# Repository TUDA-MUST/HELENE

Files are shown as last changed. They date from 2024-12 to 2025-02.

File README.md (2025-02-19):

# HELENE - low cost 6DOF robot



Open the 3D model in your browser: https://a360.co/3EGeJgL

## Summary
This repo contains everything to build and use the low cost robot except the custom electronics, which can be [found in the seperate repo right here](https://github.com/SrSupp/Helene_electronics)
All files and an assembly guide can be found in the hardware_build directory.
### Get started
You can either run the robot itself, or a simulation.

## Simulation
Start the simulation environment:
```
roslaunch moveit_helene start_gazebo.launch 
```
Afterwards start moveit: 
```
roslaunch moveit_helene start_moveit.launch 
```

## Real Robot

You need:
-Robot itself. [See building instructions](hardware_build/AssemblyManualOnline.pdf) \
-Ubuntu or Debian machine running ROS melodic or noetic with this package. Noetic is preferred! [See installation guide](ROS_InstallationGuide.md)\
-24v Power supply \
-USB Cable 

To start the robot arm connect Helene to 24V and wait until it is fully aligned. Only then can the robot arm be connected to the computer via the USB cable! 
A terminal can then be started on the computer (Preffered!). Via the command: 

```
roslaunch applications_helene realrobot.launch 
```

the connection is established automatically, the PID controller and MoveIt are started. 

Alternatively, this can also be done separately via the commands: 
```
$ roslaunch controller_helene robot.launch 
$ roslaunch moveit_helene hardware_interface.launch 
$ roslaunch moveit_helene demo.launch 
```
each of which must be executed in a new terminal. 

## Start Demo
In applications_helene you can find 2 simple nodes to control the robot. Run using:
```
$ rosrun applications_helene demoSpiral 
$ rosrun applications_helene demoSpeed
```
demoSpiral draws a spiral, demoSpeed executes the same trajectory in full and reduced speed.

## Python Interface

Inside the applications_helene\scripts folder is the Python library helpy, which allows easy programming of the robot arm. An example is located in main. When the example is executed, the robot arm should move and also the LEDs should light up. Use this script as inspiration and show what the robot arm can do!\
We use the PyCharm IDE for Python programming, with which the created scripts can be executed directly. This is also great for students. 
Without an IDE, the script main can be executed by the command: 
```
python3 main.py
```

## jog Arm with a joystick/spacemouse or published EEF velocities
You probably need to modify /moveit_helene/config/helene_servoing.yaml 

- launch either Gazebo or the real robot
- move out of singularity, if starting in one

**switch from trajectory controller to group controller**
```
rosservice call helene/controller_manager/switch_controller "start_controllers: ['effort_group']
stop_controllers: ['arm_controller']
strictness: 2
start_asap: false
timeout: 0.0" 
```
**run the servo node**
```
roslaunch moveit_helene spacenav_cpp.launch 
```

### Support for custom end effectors

The robot supports the use of custom end effectors. These end effectors can be used by adding the argument "end_effector:=END_EFFECTOR_NAME", when launching the robot.

For more information regarding custom end effectors see the [corresponding documentation](helene_ros/src/end_effectors/custom_end_effectors.md).

### Troubleshooting

If you encounter problems while compiling the ESP projects and get an error due to missing ros_lib headers, try building your customized libs like this:

```
cd <Path to the failing project>/lib
rm -rf ros_lib 
rosrun rosserial_arduino make_libraries.py .
```

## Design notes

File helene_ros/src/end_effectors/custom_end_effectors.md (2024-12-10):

# Custom end effectors for HELENE

## Usage

The helene robot supports the use of custom end effectors. These end effectors can be used by adding the argument "end_effector:=END_EFFECTOR_NAME", when launching the robot.

Here are two examples:
```
roslaunch applications_helene simulation.launch end_effector:=led_head
roslaunch applications_helene realrobot.launch end_effector:=needle
```

## Creating/adding custom end effectors

You can create or add new custom end effectors to the robot. This is done by adding a new ROS package containing the urdf description.

### Package structure
The package should have the following structure:
The name of the package should be the same name as your end effector.
For a clear project structure it is preferable to locate the package inside the /end_effectors folder, although this is not mandatory.
The package must contain a folder called urdf.
Inside this folder the description of your end effector must be stored in a file called: "END_EFFECTOR_NAME.urdf.xacro".

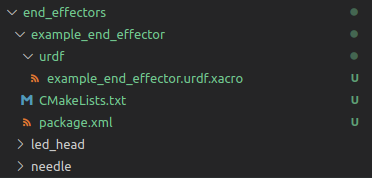
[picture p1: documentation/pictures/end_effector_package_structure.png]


If you want to use a package that does not have the same name as your end effector, you have to specify its name by adding the argument "end_effector_package:=END_EFFECTOR_PACKAGE", when launching the robot.
```
roslaunch applications_helene simulation.launch end_effector:=led_head end_effector_package:=example_package
```

### End effector description

To attach your end effector to the robot, your urdf.xacro file must include a static joint connecting your end effector with the last link of the helene robot arm (axis_0).
When defining this link, make sure that your geometry does not interfere with the geometry of the arm, as this can lead to problems with moveit path planning (0.1mm of clearance is usually sufficient).
You should also be aware that the current moveit configuration only works with static end effectors. If you want to use a dynamic end effector like a gripper, you will have to create and integrate a new moveit configuration.

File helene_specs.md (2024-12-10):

# Specifications

## Workspace

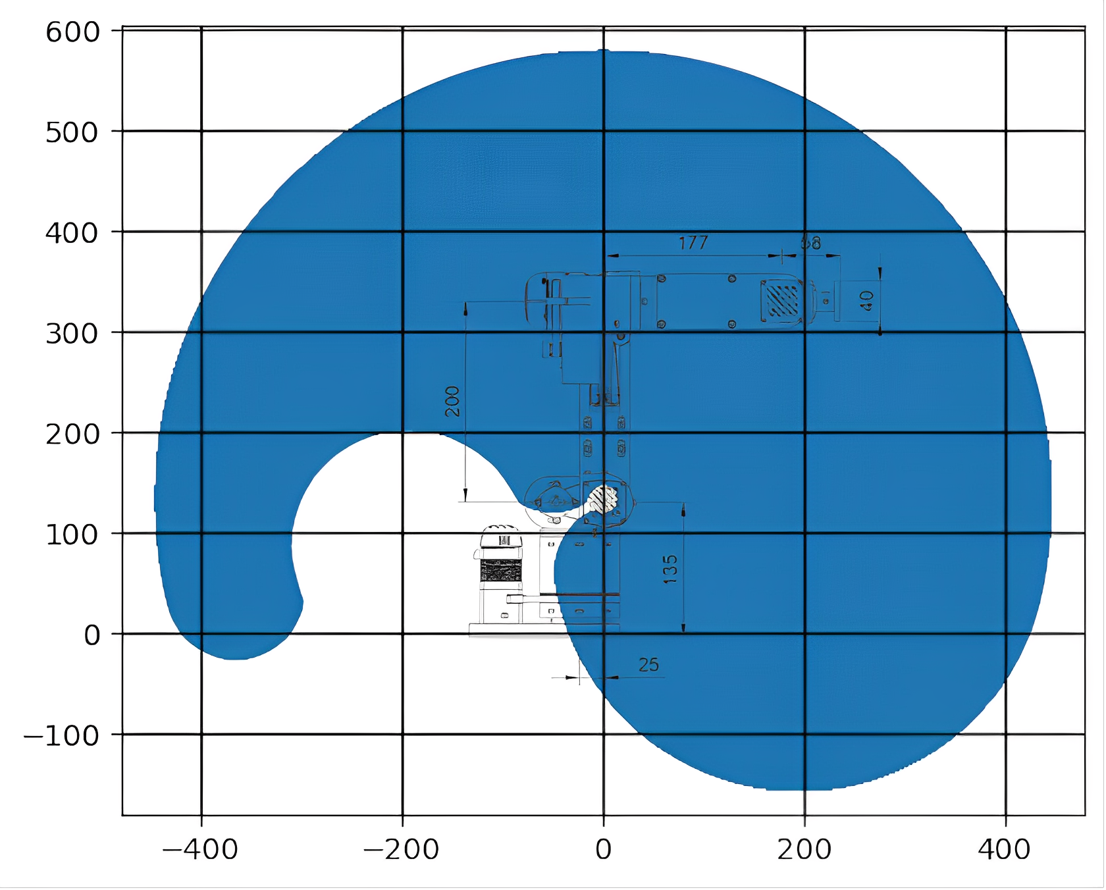
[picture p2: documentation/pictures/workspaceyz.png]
 
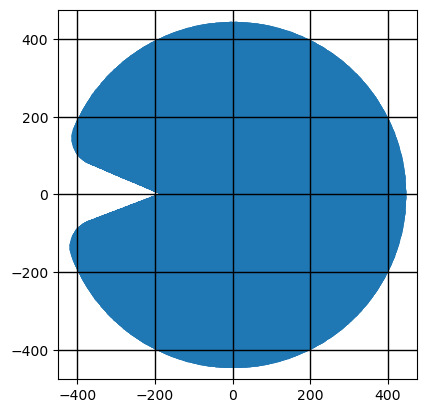
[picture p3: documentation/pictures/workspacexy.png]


The workspace in the yz- and xy-planes. 

Joint limits:

| (degrees) | 1 | 2 | 3 | 4 | 5 | 6 |
| --- | ----- | ----- | --- | ----- | ----- | ----- |
| | \-160 | \-105 | 0 | \-166 | \-155 | \-180 |
| | 160 | 105 | 160 | 166 | 155 | 180 |

## Accuracy and Precision

Accuracy and precision measurements are carried out according to ISO 9283, with small adjustments to the points. 

The following points in Helene coordinates (mm) are used:

| (mm) | home | 1 | 2 | 3 | 4 | 5 |
| ---- | ---- | --- | --- | ----- | ----- | ----- |
| x | 247  |  326.2 | 36.3 | 181.5 | 326.7 |  36.3 |
| y | 0  | -145.2 | -145.2 | 0 | 145.2 | 145.2 |
| z | 345  |  76.3  |  366.7 | 221.5 | 76.3  | 366.7 |

### Repeatability

| (mm)  | home  | 1 | 2 | 3 | 4 | 5 | average |
| ----- | ----- | ----- | ----- | ----- | ----- | ----- | --- |
| x | 0.14  | 0.269 | 0.256 | 0.089 | 0.688 | 0.754 | |
| y | 0.173 | 0.155 | 0.116 | 0.111 | 0.837 | 2.556 | |
| z | 0.255 | 0.131 | 0.111 | 0.112 | 0.69  | 0.813 | |
| total | 0.338 | 0.337 | 0.302 | 0.181 | 1.285 | 2.786 |  **0.872** |

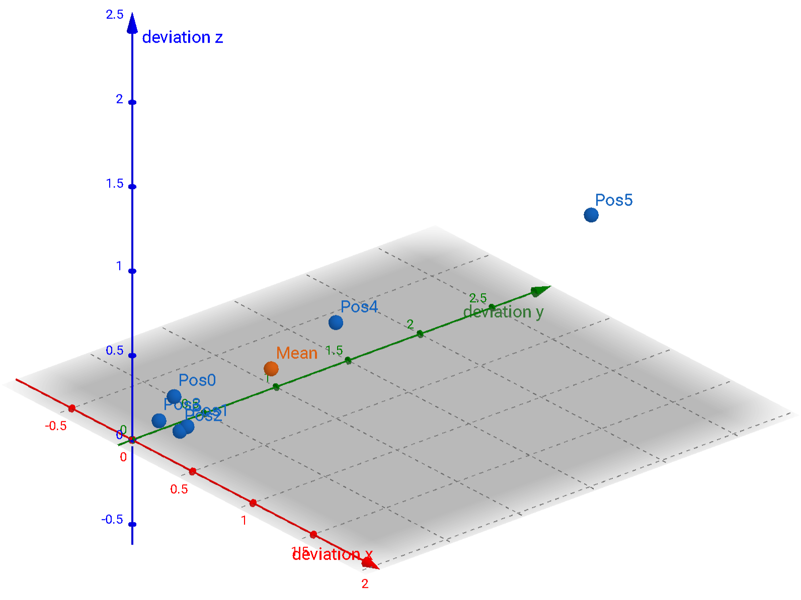
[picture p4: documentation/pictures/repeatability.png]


### Positional Accuracy

The positional accuracy is evaluated at the same positions as repeatability. The home position of Helene is assumed to be true, and positions are evaluated relative to it.

| (mm)  | 1 | 2 | 3 | 4 | 5 | average |
| ----- | --- | --- | --- | --- | --- | --- |
| x | -1.615 |  5.228 |  0.204 | -8.302 |  6.085 | |
| y |  9.178 | -3.643 | -4.362 | -0.038 | 10.397 | |
| z | -2.919 |  2.646 | -2.133 |  0.776 | -1.148 | |
| total |  9.765 |  6.900 |  4.860 |  8.338 | 12.101 |  **8.393** |

Thank you to WENZEL Group for allowing us to use their coordinate measuring machines and assisting in the evaluation of the robot. 

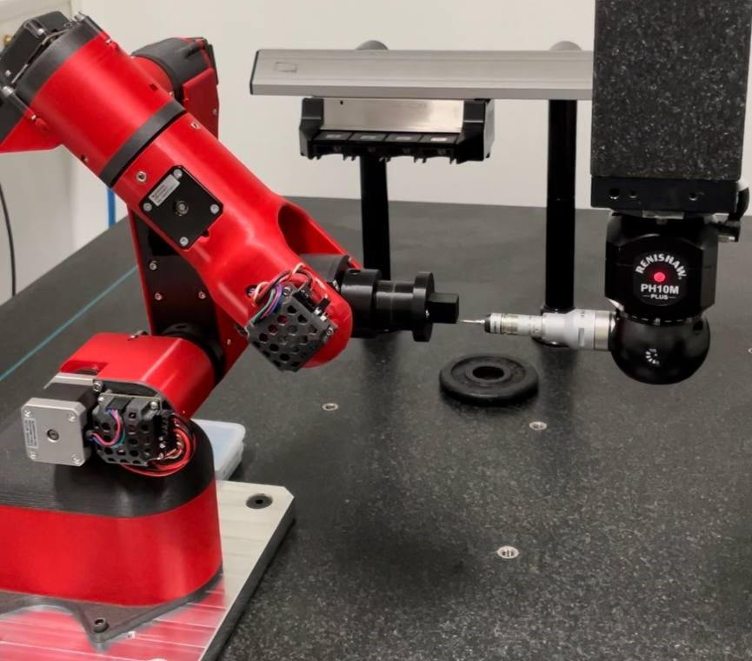
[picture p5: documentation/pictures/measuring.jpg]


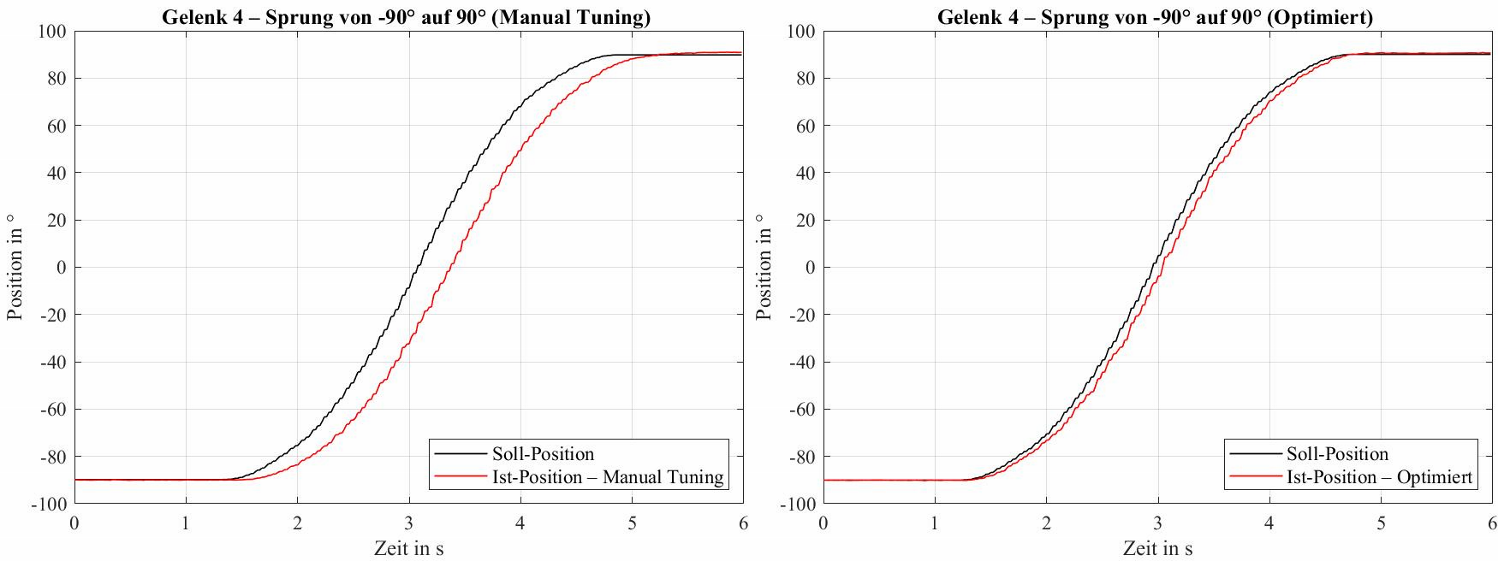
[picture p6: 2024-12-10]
documentation/pictures/controller_comparison.PNG

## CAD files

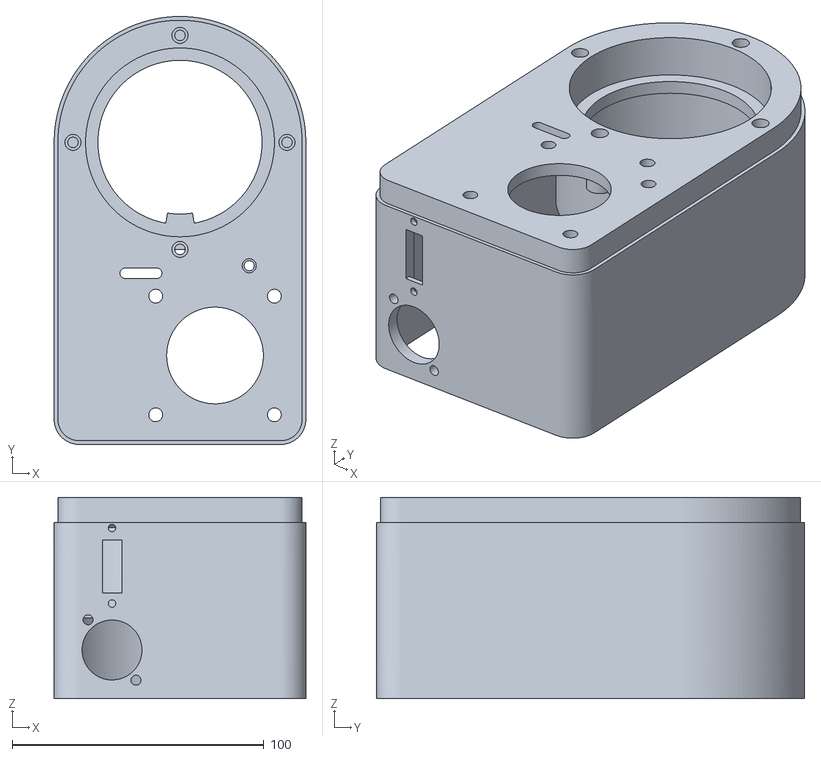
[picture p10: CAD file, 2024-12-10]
hardware_build/print files/col1/B1_Basis_Main.stl
100.0 x 170.0 x 80.0

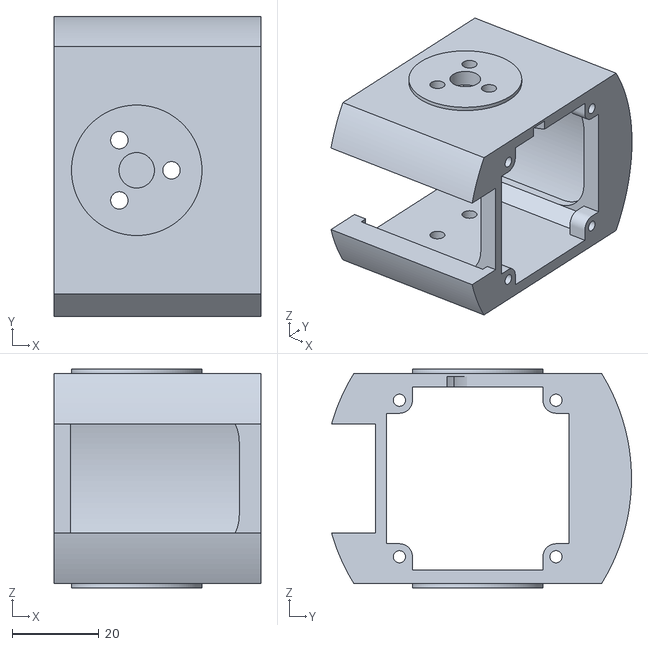
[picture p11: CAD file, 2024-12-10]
hardware_build/print files/col2/B33_Gelenk6_main.stl
47.6 x 69.0 x 50.3

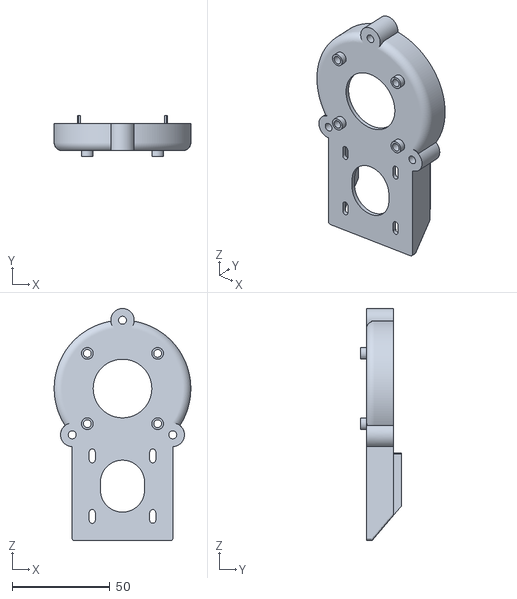
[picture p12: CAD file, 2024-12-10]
hardware_build/print files/col2/B25_Gelenk4_Motorhalter.stl
70.0 x 21.0 x 118.8

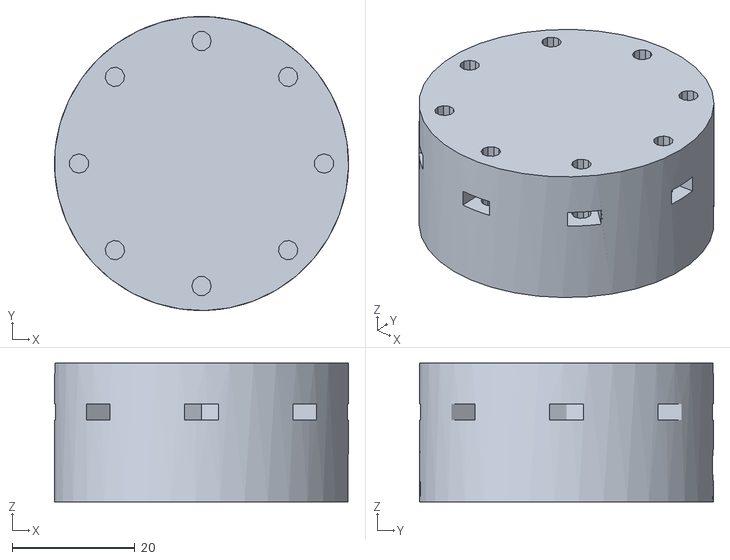
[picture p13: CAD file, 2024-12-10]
helene_ros/src/hw_description/meshes/Flansch.stl
48.0 x 48.0 x 22.7

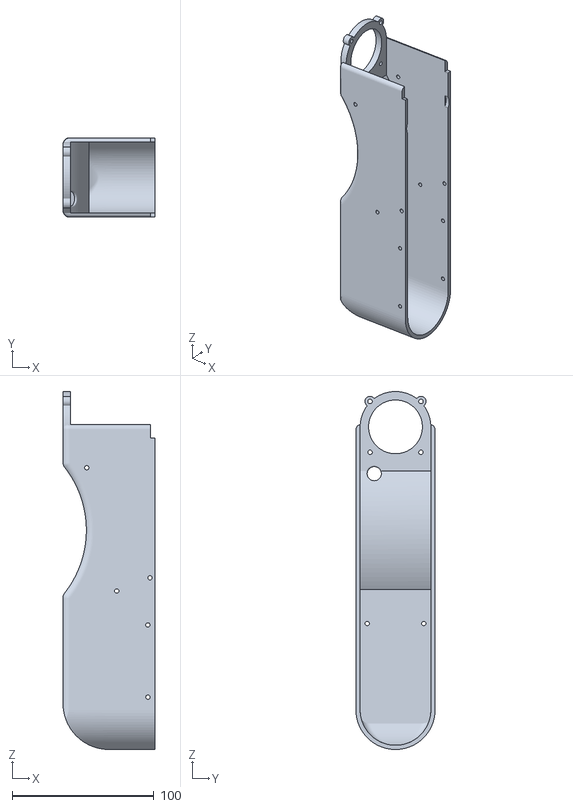
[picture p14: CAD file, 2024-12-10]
hardware_build/print files/col1/B22_Gelenk3_Deckel.stl
65.0 x 56.0 x 253.0

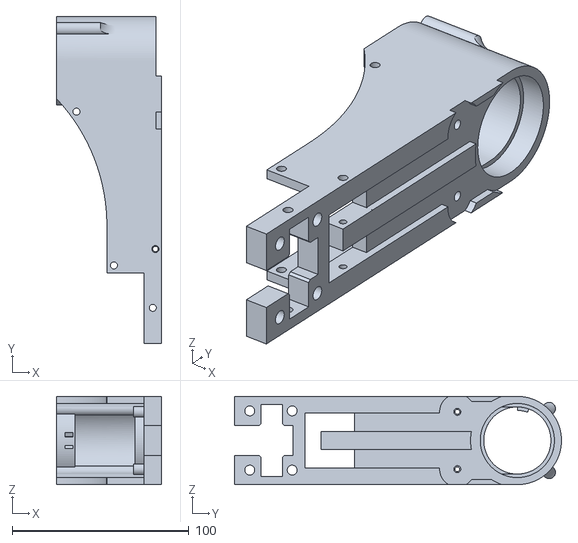
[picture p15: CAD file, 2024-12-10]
hardware_build/print files/col2/B16_Gelenk3_Hauptteil_Oben.stl
59.6 x 185.2 x 50.0

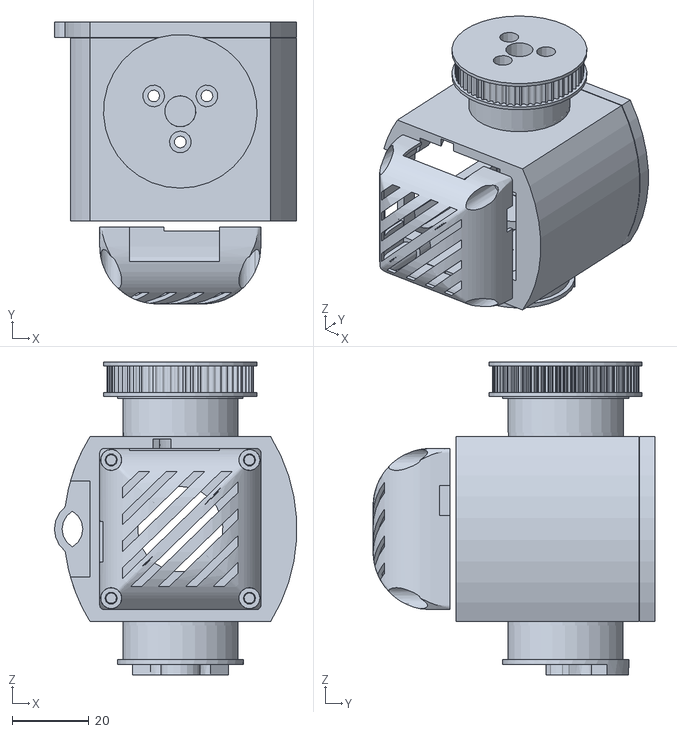
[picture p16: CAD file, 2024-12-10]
helene_ros/src/hw_description/meshes/Komponente6.stl
63.1 x 73.4 x 81.5

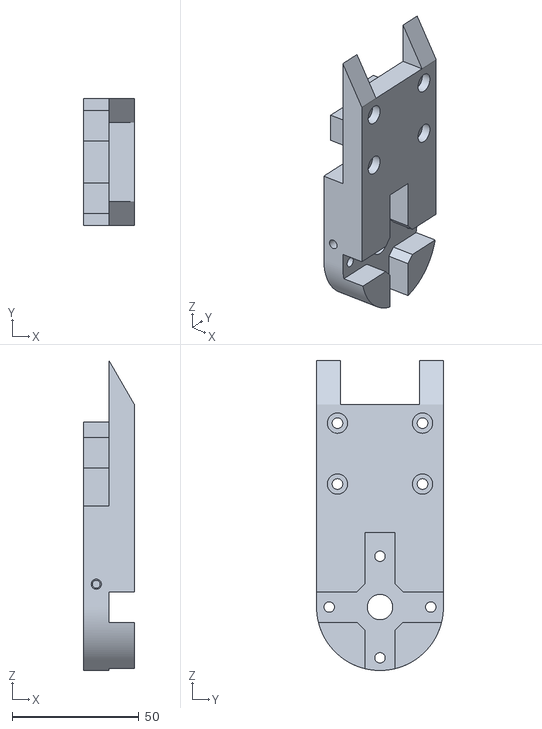
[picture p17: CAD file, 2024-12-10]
hardware_build/print files/col2/B15_Gelenk3_Hauptteil_Unten.stl
20.0 x 50.0 x 122.1

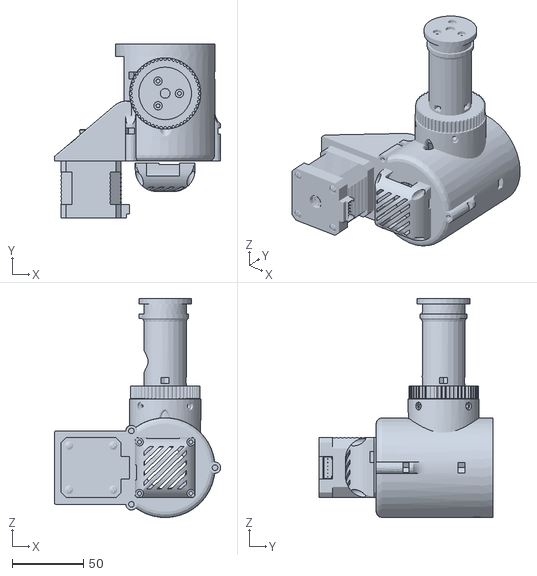
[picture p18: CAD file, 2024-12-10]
helene_ros/src/hw_description/meshes/Komponente4.stl
116.8 x 122.4 x 153.7

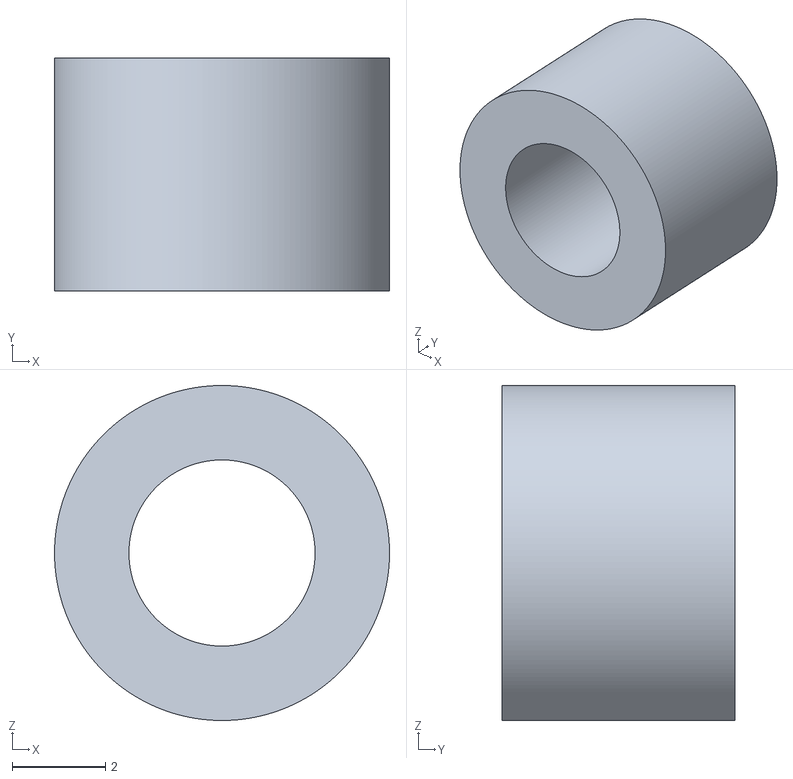
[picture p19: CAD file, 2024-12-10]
hardware_build/print files/col2/B36_Lagerabstand.stl
7.20 x 5.00 x 7.20

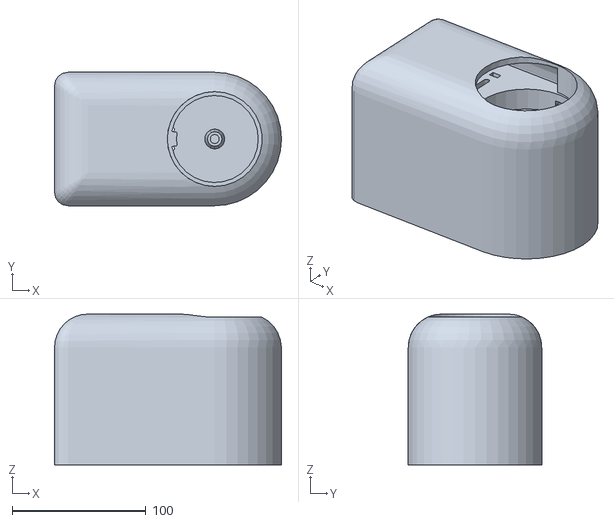
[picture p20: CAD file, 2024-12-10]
helene_ros/src/hw_description/meshes/Komponente1.stl
170.0 x 100.0 x 113.0

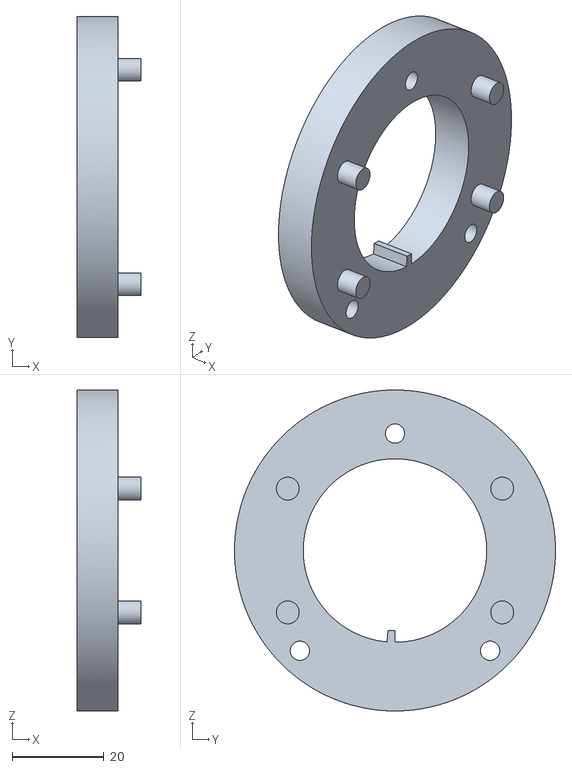
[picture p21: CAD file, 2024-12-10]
hardware_build/print files/col2/B27_Gelenk4_Lagerdeckel.stl
14.0 x 70.0 x 70.0

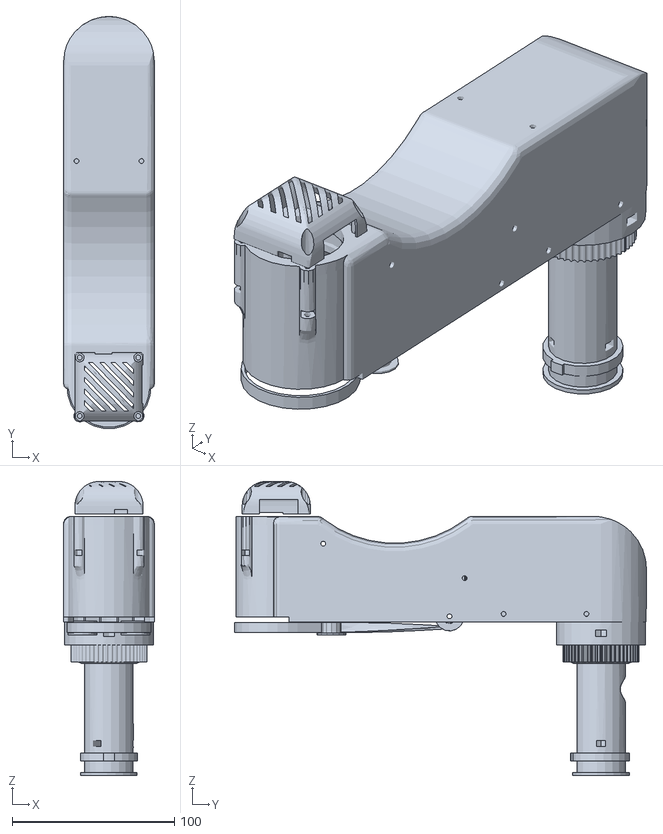
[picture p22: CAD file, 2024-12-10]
helene_ros/src/hw_description/meshes/Komponente3.stl
56.0 x 253.7 x 181.1

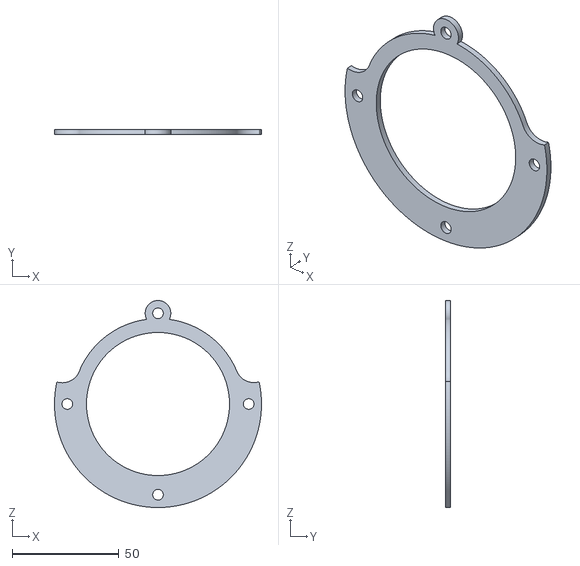
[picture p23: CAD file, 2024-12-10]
hardware_build/print files/col2/B3_Basis_Lagerdecke.stl
97.0 x 2.50 x 97.0

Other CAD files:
helene_ros/src/hw_description/meshes/Komponente5.stl
hardware_build/print files/col2/B34_Gelenk6_Deckel.stl
hardware_build/print files/col2/B20_Gelenk3_Welle_Abschluss.stl
hardware_build/print files/col2/B6_Basis_Pulley_klein2.stl
hardware_build/print files/col2/B12_Gelenk2_Festlager_Gelenkfassung.stl
hardware_build/print files/col2/B13_Gelenk2_Welle_Abschluss.stl
hardware_build/print files/col2/B14_Gelenk2_Lagerdecke.stl
hardware_build/print files/col2/B21_Gelenk3_Motorhalter.stl
hardware_build/print files/col2/B26_Gelenk4_Pulley.stl
hardware_build/print files/col2/B28_Gelenk4_5_Ubergang.stl
hardware_build/print files/col2/B30_Gelenk5_Welle.stl
hardware_build/print files/col2/B35_Deckel_Elektronik.stl
hardware_build/print files/col2/B5_Basis_Pulley_klein.stl
hardware_build/print files/col2/B7_Basis_Bodenplatte.stl

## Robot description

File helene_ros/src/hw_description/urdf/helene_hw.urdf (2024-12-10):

<?xml version="1.0" ?>
<robot name="helene">
    <link name="world" />

  <joint name="world_to_base_link" type="fixed">
    <parent link="world"/>
    <child link="base_link"/>
  </joint>
    <link name="base_link">
        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
        
<inertial>
            <mass value="0.8" />
            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
        </inertial>

    </link>
    <link name="axis_0">
        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
        
<inertial>
            <mass value="0.8" />
            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
        </inertial>

    </link>
    <joint name="q1" type="revolute">
        <axis xyz="0 0 1" />
        <limit effort="1000.0" lower="-2.79" upper="2.79" velocity="5" />
        <origin rpy="0 0 0" xyz="0 0 0" />
        <parent link="base_link" />
        <child link="axis_0" />
    </joint>
    <link name="axis_1">
        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
        
<inertial>
            <mass value="0.8" />
            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
        </inertial>

    </link>
    <joint name="q2" type="revolute">
        <axis xyz="0 0 1" />
        <limit effort="1000.0" lower="-1.83" upper="1.83" velocity="5" />
        <origin rpy="-1.571 0 0" xyz="0.02 0 0.145" />
        <parent link="axis_0" />
        <child link="axis_1" />
    </joint>
    <link name="axis_2">
        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
        
<inertial>
            <mass value="0.8" />
            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
        </inertial>

    </link>
    <joint name="q3" type="revolute">
        <axis xyz="0 0 1" />
        <limit effort="1000.0" lower="0" upper="2.7925" velocity="5" />
        <origin rpy="0 0 3.141" xyz="0 -0.200 0" />
        <parent link="axis_1" />
        <child link="axis_2" />
    </joint>
    <link name="axis_3">
        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
        
<inertial>
            <mass value="0.8" />
            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
        </inertial>

    </link>
    <joint name="q4" type="revolute">
        <axis xyz="0 0 1" />
        <limit effort="1000.0" lower="-2.9" upper="2.9" velocity="5" />
        <origin rpy="-1.571 0 0" xyz="0 0 0" />
        <parent link="axis_2" />
        <child link="axis_3" />
    </joint>
    <link name="axis_4">
        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
        
<inertial>
            <mass value="0.8" />
            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
        </inertial>

    </link>
    <joint name="q5" type="revolute">
        <axis xyz="0 0 1" />
        <limit effort="1000.0" lower="-2.7" upper="2.7" velocity="5" />
        <origin rpy="1.571 0 0" xyz="0 0 0.177" />
        <parent link="axis_3" />
        <child link="axis_4" />
    </joint>
    <link name="axis_5">
        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
        
<inertial>
            <mass value="0.8" />
            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
        </inertial>

    </link>
    <joint name="q6" type="revolute">
        <axis xyz="0 0 1" />
        <limit effort="1000.0" lower="-3.141" upper="3.141" velocity="5" />
        <origin rpy="-1.571 0 0" xyz="0 0 0" />
        <parent link="axis_4" />
        <child link="axis_5" />
    </joint>
    <link name="axis_6">
        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
    </link>
    <joint name="q7" type="fixed">
        <axis xyz="0 0 1" />
        <origin rpy="0 0 0" xyz="0 0 0.05" />
        <parent link="axis_5" />
        <child link="axis_6" />
    </joint>
    
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
</robot>

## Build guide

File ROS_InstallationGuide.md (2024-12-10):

# Instructions for installing ROS and the Helene package

Installing ROS with all the associated packages and setting up a catkin-compatible workspace is actually not difficult, but can seem overwhelming at first glance. Therefore, the most important steps are summarized here. 

It is assumed that you have a computer with Debian Buster or Ubuntu 20.04. 

## Installing ROS

An installation guide for the basic installation of ROS noetic [can be found here](http://wiki.ros.org/noetic/Installation). It is recommended to do the full desktop installation. Please do not forget the "Environment setup" step!

However, after the successful installation, there are still some packages missing that are required to run Helene. Install all of them via this command:
```
sudo apt install ros-noetic-desktop ros-noetic-catkin python3-catkin-tools python3-osrf-pycommon ros-noetic-rosserial-arduino ros-noetic-rosserial ros-noetic-controller-manager ros-noetic-moveit ros-noetic-moveit-visual-tools ros-noetic-ros-control  ros-noetic-ros-controllers python3-rosdep
```
Also, it is recommended to install [Visual Studio Code](https://code.visualstudio.com/docs/setup/linux) to be able to edit Helene's ROS package. 

## Installing and Configuring Your ROS Environment

First let's create and build a [catkin workspace](http://wiki.ros.org/catkin/workspaces):
```
$ mkdir -p ~/ros_ws/src
$ cd ~/ros_ws/
$ catkin build
```
Then source this directory: 
```
echo "source ~/ros_ws/devel/setup.bash" >> ~/.bashrc
```
Afterwards clone this repo:
```
$ cd src
$ git clone https://github.com/felixherbst/helene_hardware
```
Then compile everything:
```
$ cd ~/ros_ws
$ catkin build
```

Congratulations! You should be ready to rock now

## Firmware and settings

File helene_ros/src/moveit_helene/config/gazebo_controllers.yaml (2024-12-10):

controller_list:
 - name: helene/arm_controller
   action_ns: follow_joint_trajectory
   default: True
   type: FollowJointTrajectory
   joints:
      - q1
      - q2
      - q3
      - q4
      - q5
      - q6
 - name: helene/effort_group
   action_ns: follow_joint_trajectory
   default: True
   type: FollowJointTrajectory
   joints:
      - q1
      - q2
      - q3
      - q4
      - q5
      - q6

helene:
    joint_state_controller:
      type: joint_state_controller/JointStateController
      publish_rate: 50
    arm_controller:
        type: effort_controllers/JointTrajectoryController
        joints:
          - q1
          - q2
          - q3
          - q4
          - q5
          - q6

        gains:
          q1: {p: 8000, i: 180, d: 160}
          q2: {p: 70000, i: 800, d: 740}
          q3: {p: 18000, i: 200, d: 180}
          q4: {p: 16000, i: 160, d: 140}
          q5: {p: 10000, i: 80, d: 100}
          q6: {p: 8000, i: 60, d: 80}

        

    effort_group:
      type: effort_controllers/JointGroupPositionController
      joints:
        - q1
        - q2
        - q3
        - q4
        - q5
        - q6
      q1: 
        pid: {p: 8000, i: 180, d: 160}
      q2: 
        pid: {p: 70000, i: 800, d: 740}
      q3: 
        pid: {p: 18000, i: 200, d: 180}
      q4: 
        pid: {p: 16000, i: 160, d: 140}
      q5: 
        pid: {p: 10000, i: 80, d: 100}
      q6: 
        pid: {p: 8000, i: 60, d: 80}

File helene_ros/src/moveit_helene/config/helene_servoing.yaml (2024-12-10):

###############################################
# Modify all parameters related to servoing here
###############################################
use_gazebo: true # Whether the robot is started in a Gazebo simulation environment

## Properties of incoming commands
command_in_type: "speed_units" # "unitless"> in the range [-1:1], as if from joystick. "speed_units"> cmds are in m/s and rad/s
scale:
  # Scale parameters are only used if command_in_type=="unitless"
  linear:  0.6  # Max linear velocity. Meters per publish_period. Unit is [m/s]. Only used for Cartesian commands.
  rotational:  1 # Max angular velocity. Rads per publish_period. Unit is [rad/s]. Only used for Cartesian commands.
  # Max joint angular/linear velocity. Rads or Meters per publish period. Only used for joint commands on joint_command_in_topic.
  joint: 0.03
low_pass_filter_coeff: 2.  # Larger --> trust the filtered data more, trust the measurements less.

## Properties of outgoing commands
publish_period: 0.004  # 1/Nominal publish rate [seconds]
low_latency_mode: false  # Set this to true to publish as soon as an incoming Twist command is received (publish_period is ignored)

# What type of topic does your robot driver expect?
# Currently supported are std_msgs/Float64MultiArray (for ros_control JointGroupVelocityController or JointGroupPositionController)
# or trajectory_msgs/JointTrajectory (for Universal Robots and other non-ros_control robots)
command_out_type: std_msgs/Float64MultiArray

# What to publish? Can save some bandwidth as most robots only require positions or velocities
publish_joint_positions: true
publish_joint_velocities: false
publish_joint_accelerations: false

## MoveIt properties
move_group_name:  helene_arm  # Often 'manipulator' or 'arm'
planning_frame: world  # The MoveIt planning frame. Often 'base_link' or 'world'

## Other frames
ee_frame_name: axis_6  # The name of the end effector link, used to return the EE pose
robot_link_command_frame:  world  # commands must be given in the frame of a robot link. Usually either the base or end effector

## Stopping behaviour
incoming_command_timeout:  0.1  # Stop servoing if X seconds elapse without a new command
# If 0, republish commands forever even if the robot is stationary. Otherwise, specify num. to publish.
# Important because ROS may drop some messages and we need the robot to halt reliably.
num_outgoing_halt_msgs_to_publish: 4

## Configure handling of singularities and joint limits
lower_singularity_threshold:  17  # Start decelerating when the condition number hits this (close to singularity)
hard_stop_singularity_threshold: 30 # Stop when the condition number hits this
joint_limit_margin: 0.2 # added as a buffer to joint limits [radians]. If moving quickly, make this larger.

## Topic names
cartesian_command_in_topic: servo_server/delta_twist_cmds  # Topic for incoming Cartesian twist commands
joint_command_in_topic: servo_server/delta_joint_cmds # Topic for incoming joint angle commands
joint_topic: joint_states
status_topic: status # Publish status to this topic
command_out_topic: /helene/effort_group/command # Publish outgoing commands here

## Collision checking for the entire robot body
check_collisions: false # Check collisions?
collision_check_rate: 50 # [Hz] Collision-checking can easily bog down a CPU if done too often.
# Two collision check algorithms are available:
# "threshold_distance" begins slowing down when nearer than a specified distance. Good if you want to tune collision thresholds manually.
# "stop_distance" stops if a collision is nearer than the worst-case stopping distance and the distance is decreasing. Requires joint acceleration limits
collision_check_type: threshold_distance
# Parameters for "threshold_distance"-type collision checking
self_collision_proximity_threshold: 0.01 # Start decelerating when a self-collision is this far [m]
scene_collision_proximity_threshold: 0.05 # Start decelerating when a scene collision is this far [m]
# Parameters for "stop_distance"-type collision checking
collision_distance_safety_factor: 1000 # Must be >= 1. A large safety factor is recommended to account for latency
min_allowable_collision_distance: 0.01 # Stop if a collision is closer than this [m]

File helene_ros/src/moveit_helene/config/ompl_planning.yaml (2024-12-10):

planner_configs:
  SBL:
    type: geometric::SBL
    range: 0.0  # Max motion added to tree. ==> maxDistance_ default: 0.0, if 0.0, set on setup()
  EST:
    type: geometric::EST
    range: 0.0  # Max motion added to tree. ==> maxDistance_ default: 0.0, if 0.0 setup()
    goal_bias: 0.05  # When close to goal select goal, with this probability. default: 0.05
  LBKPIECE:
    type: geometric::LBKPIECE
    range: 0.0  # Max motion added to tree. ==> maxDistance_ default: 0.0, if 0.0, set on setup()
    border_fraction: 0.9  # Fraction of time focused on boarder default: 0.9
    min_valid_path_fraction: 0.5  # Accept partially valid moves above fraction. default: 0.5
  BKPIECE:
    type: geometric::BKPIECE
    range: 0.0  # Max motion added to tree. ==> maxDistance_ default: 0.0, if 0.0, set on setup()
    border_fraction: 0.9  # Fraction of time focused on boarder default: 0.9
    failed_expansion_score_factor: 0.5  # When extending motion fails, scale score by factor. default: 0.5
    min_valid_path_fraction: 0.5  # Accept partially valid moves above fraction. default: 0.5
  KPIECE:
    type: geometric::KPIECE
    range: 0.0  # Max motion added to tree. ==> maxDistance_ default: 0.0, if 0.0, set on setup()
    goal_bias: 0.05  # When close to goal select goal, with this probability. default: 0.05
    border_fraction: 0.9  # Fraction of time focused on boarder default: 0.9 (0.0,1.]
    failed_expansion_score_factor: 0.5  # When extending motion fails, scale score by factor. default: 0.5
    min_valid_path_fraction: 0.5  # Accept partially valid moves above fraction. default: 0.5
  RRT:
    type: geometric::RRT
    range: 0.0  # Max motion added to tree. ==> maxDistance_ default: 0.0, if 0.0, set on setup()
    goal_bias: 0.05  # When close to goal select goal, with this probability? default: 0.05
  RRTConnect:
    type: geometric::RRTConnect
    range: 0.0  # Max motion added to tree. ==> maxDistance_ default: 0.0, if 0.0, set on setup()
  RRTstar:
    type: geometric::RRTstar
    range: 0.0  # Max motion added to tree. ==> maxDistance_ default: 0.0, if 0.0, set on setup()
    goal_bias: 0.05  # When close to goal select goal, with this probability? default: 0.05
    delay_collision_checking: 1  # Stop collision checking as soon as C-free parent found. default 1
  TRRT:
    type: geometric::TRRT
    range: 0.0  # Max motion added to tree. ==> maxDistance_ default: 0.0, if 0.0, set on setup()
    goal_bias: 0.05  # When close to goal select goal, with this probability? default: 0.05
    max_states_failed: 10  # when to start increasing temp. default: 10
    temp_change_factor: 2.0  # how much to increase or decrease temp. default: 2.0
    min_temperature: 10e-10  # lower limit of temp change. default: 10e-10
    init_temperature: 10e-6  # initial temperature. default: 10e-6
    frountier_threshold: 0.0  # dist new state to nearest neighbor to disqualify as frontier. default: 0.0 set in setup()
    frountierNodeRatio: 0.1  # 1/10, or 1 nonfrontier for every 10 frontier. default: 0.1
    k_constant: 0.0  # value used to normalize expresssion. default: 0.0 set in setup()
  PRM:
    type: geometric::PRM
    max_nearest_neighbors: 10  # use k nearest neighbors. default: 10
  PRMstar:
    type: geometric::PRMstar
  FMT:
    type: geometric::FMT
    num_samples: 1000  # number of states that the planner should sample. default: 1000
    radius_multiplier: 1.1  # multiplier used for the nearest neighbors search radius. default: 1.1
    nearest_k: 1  # use Knearest strategy. default: 1
    cache_cc: 1  # use collision checking cache. default: 1
    heuristics: 0  # activate cost to go heuristics. default: 0
    extended_fmt: 1  # activate the extended FMT*: adding new samples if planner does not finish successfully. default: 1
  BFMT:
    type: geometric::BFMT
    num_samples: 1000  # number of states that the planner should sample. default: 1000
    radius_multiplier: 1.0  # multiplier used for the nearest neighbors search radius. default: 1.0
    nearest_k: 1  # use the Knearest strategy. default: 1
    balanced: 0  # exploration strategy: balanced true expands one tree every iteration. False will select the tree with lowest maximum cost to go. default: 1
    optimality: 1  # termination strategy: optimality true finishes when the best possible path is found. Otherwise, the algorithm will finish when the first feasible path is found. default: 1
    heuristics: 1  # activates cost to go heuristics. default: 1
    cache_cc: 1  # use the collision checking cache. default: 1
    extended_fmt: 1  # Activates the extended FMT*: adding new samples if planner does not finish successfully. default: 1
  PDST:
    type: geometric::PDST
  STRIDE:
    type: geometric::STRIDE
    range: 0.0  # Max motion added to tree. ==> maxDistance_ default: 0.0, if 0.0, set on setup()
    goal_bias: 0.05  # When close to goal select goal, with this probability. default: 0.05
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
